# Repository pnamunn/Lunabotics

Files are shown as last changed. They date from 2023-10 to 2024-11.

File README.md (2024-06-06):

# NASA Lunabotics 2024 Competition - Team ARES for SDSU
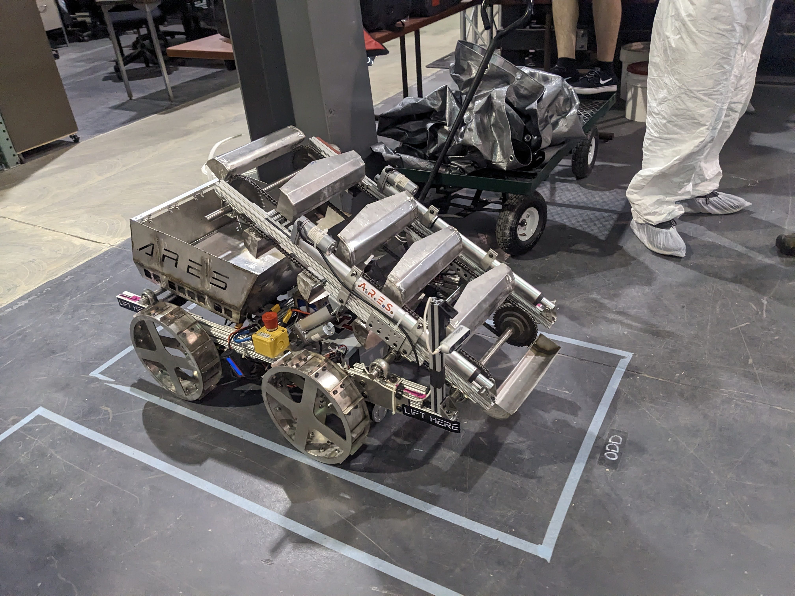
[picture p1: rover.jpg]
Rover picture


## Distros used:
Using Ubuntu 20.04 LTS on Jetson & Ubuntu 22.04 LTS on laptop.  ROS2 foxy on Jetson & ROS2 humble on laptop.  Different ROS2 versions shouldn't affect their ability to work together over a network.  
Python packages needed for controls:  rclpy, pyserial, sensor_msgs, bitarray  
Python packages needed for modified Vulcan video stream:  cv2, pyrealsense2, flask, numpy  

## Rover telecoms set up:
Ensure laptop & Jetson are both connected to the ARES_WAP

`ros2 run joy joy_node` on laptop to detect Logitech controller

`minicom -D /dev/<arduino_USB_port> -b 500000` on Jetson to serial monitor the Arduino Mega

`python3 serial_joystick.py` on Jetson

<run vulcan video stream on Jetson command>

<connect to appropriate IP address to view video stream on laptop>

## Passwords:
| Device | Username | Password | |
| :---: | :---: | :---: | :---: |
| Laptop | steui | WARHAWK | |
| Jetson | stubert  | S2P@C619 | |
| WAP connection | ARES_WAP | 72878781 | |
| WAP config settings | admin | DoctorShaffar<3 | Website: tplinkwifi.net |

## On Arduino Mega hat:
J17 connects to PB6 (drivetrain R) & PB5(drivetrain L)  
J18 connects to DH3 (exc tilt) & PL4 (depo tilt)  
J19 connects to DH5 (exc height) & PH4 (exc chain)  

## Logitech controller buttons mapping:
| Control | Use |
| ---: | :---  |
| Left joystick  | Drivetrain controls |
| Right joystick | Camera gimble controls |
| B or X | Excavation chain fwd or backward |
| Y or A | Excavation frame move up or down |
| LB or LT | Depo bin tilt out or in |
| RB or RT | Excavation frame tilt out or in  |

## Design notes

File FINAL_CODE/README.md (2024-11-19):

### In competition, the following code was used to control the rover:

- serial_joystick.py : 
	- Input: ROS2 datatypes describing the current state of the gamepad's joysticks & buttons
	- Output: Encoded serial bytes of the gamepad's state changes
- ARES_Embedded.c : 
	- Input: Encoded serial bytes of the gamepad's state changes
	- Output: 16-bit PWM signals for motors & actuators
- vulcan_camera_modified.py :
	- *Input:* Frames from the Intel Realsense camera
	- *Output:* A Flask app, accessible by other devices on the same network, that shows a grayscale video stream  

### Before competition, the following code was finished and successfully tested individually, but the team did not have enough time to intergrate them with the rest of the C code on one microcontroller:

- current_sensors.c
	- Input: 
	- Output: Prints current readings from 2 sensors, as floating points with 3 sig figs
- loadcell_sensor.c
	- Input: 4 strain gauges in Wheatstone configuration, fed through the HX711 ADC/PGA
	- Output: Prints detected weight 
- proximity_sensors.c
	- Input: 
	- Output: Prints distance from detected obstacle & blocks drivetrain movement if obstacle becomes too close

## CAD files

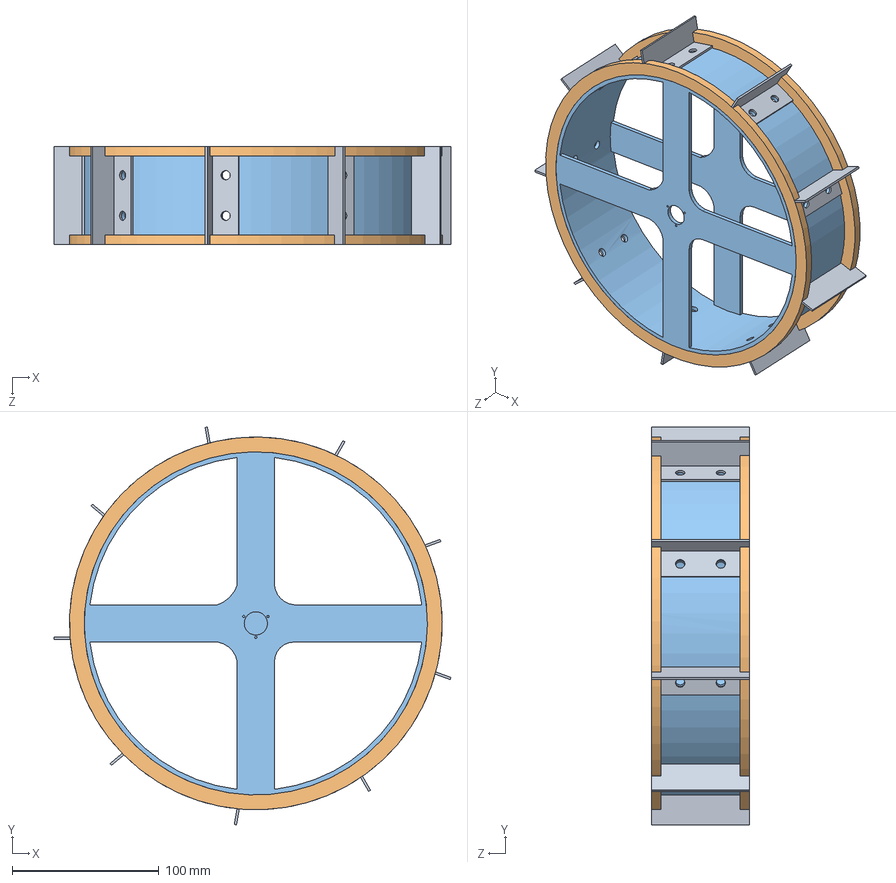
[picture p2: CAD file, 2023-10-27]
CAD/GrouserWheel/Full Grouser Wheel.SLDASM
270.5 x 271.1 x 66.7 mm
Grouser Wheel
Grouser Wheel Rim x 2
Grouser x 9

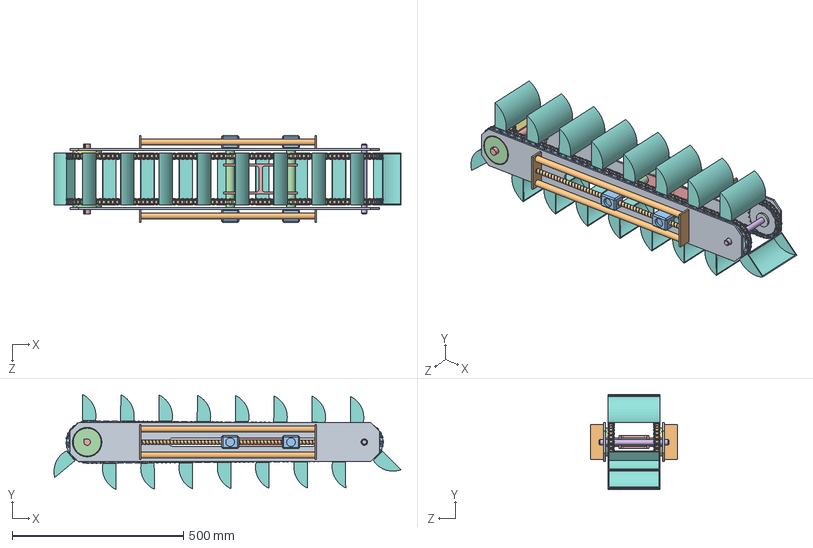
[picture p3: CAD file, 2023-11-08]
CAD/HADES CAD/Excavation/Excavation Belt Sub Asm.SLDASM
1013.8 x 277.9 x 254.0 mm
6663K201_ANSI Roller Chain Idler Sprocket x 2
7265K326_Adding Link for ANSI Number 40H Heavy Duty Roller Chain x 153
7265K324_Connecting Link for ANSI Number 40H Heavy Duty Roller Chain x 154
6236K156_Roller Chain Sprocket
Drive_Key
1346K24_Rotary Shaft
Mirror6236K156_Roller Chain Sprocket
scoop x 17
Side_Panel x 2
Linear Actuator x 2
Acuator Sleeve x 4
Fixing Rod x 2
Fixed Rod Seperator

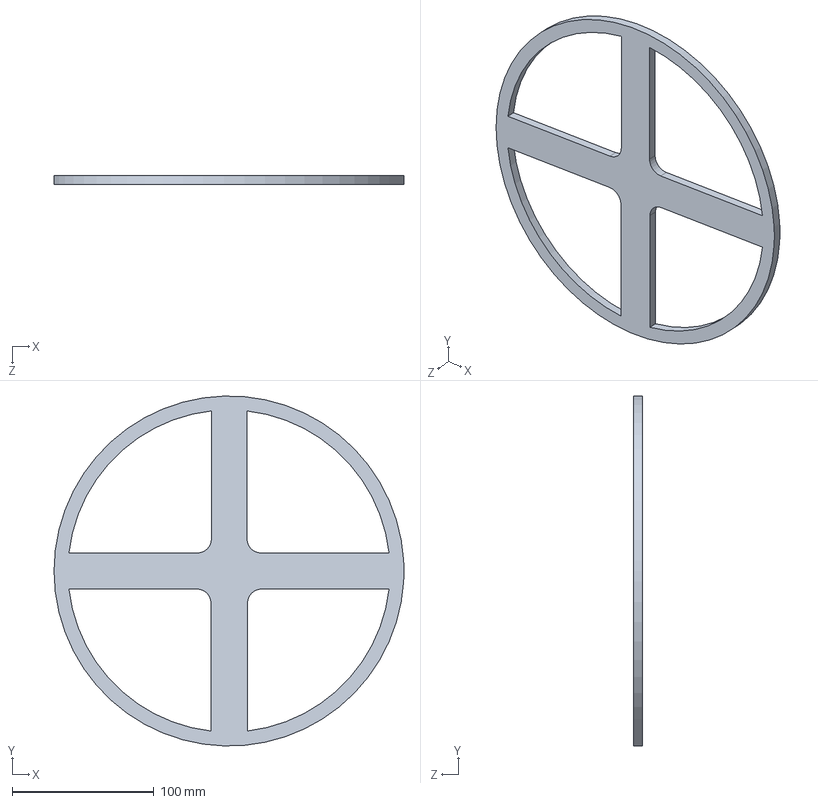
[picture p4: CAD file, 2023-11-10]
CAD/GrouserWheel/18Grouser Wheel/Grouser Wheel Rim front.SLDPRT
247.1 x 247.0 x 6.35 mm

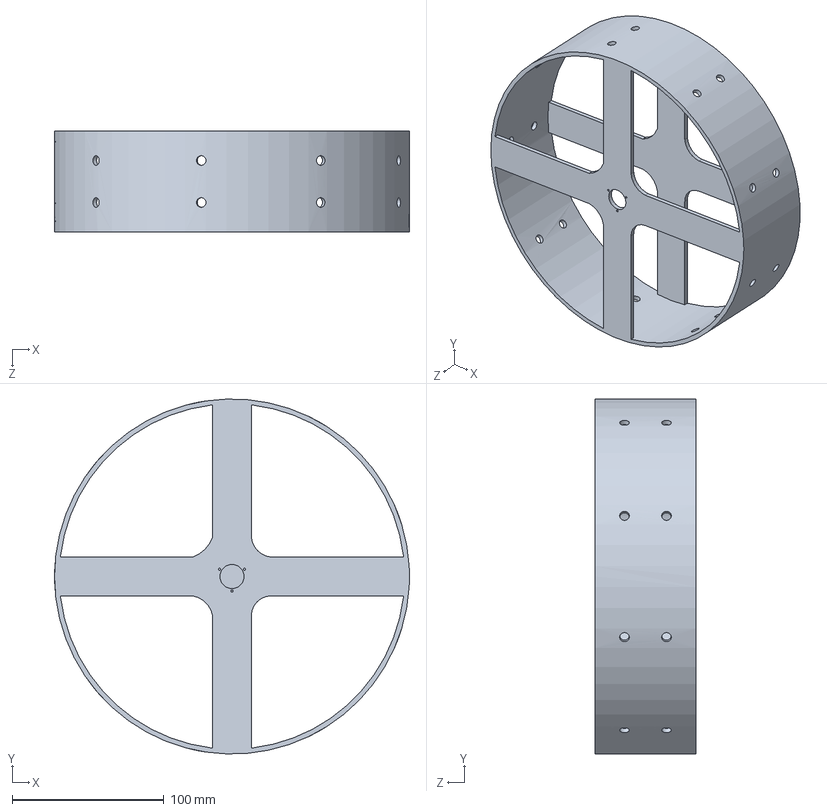
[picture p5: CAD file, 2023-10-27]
CAD/GrouserWheel/Grouser Wheel.SLDPRT
233.8 x 233.7 x 66.7 mm

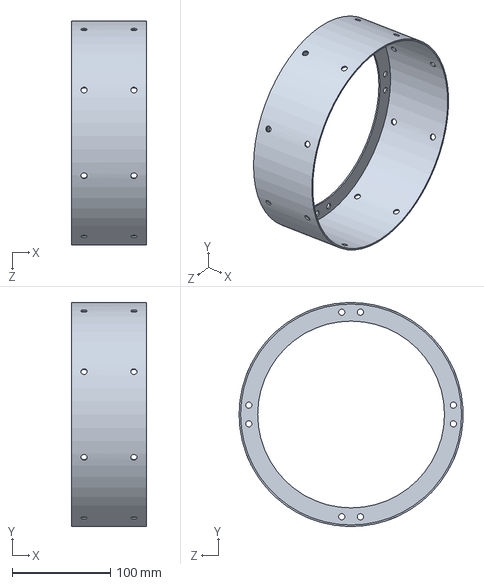
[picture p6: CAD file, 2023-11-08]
CAD/HADES CAD/Chassis/Copy of Wheel_Rim.SLDPRT
76.2 x 228.5 x 228.4 mm

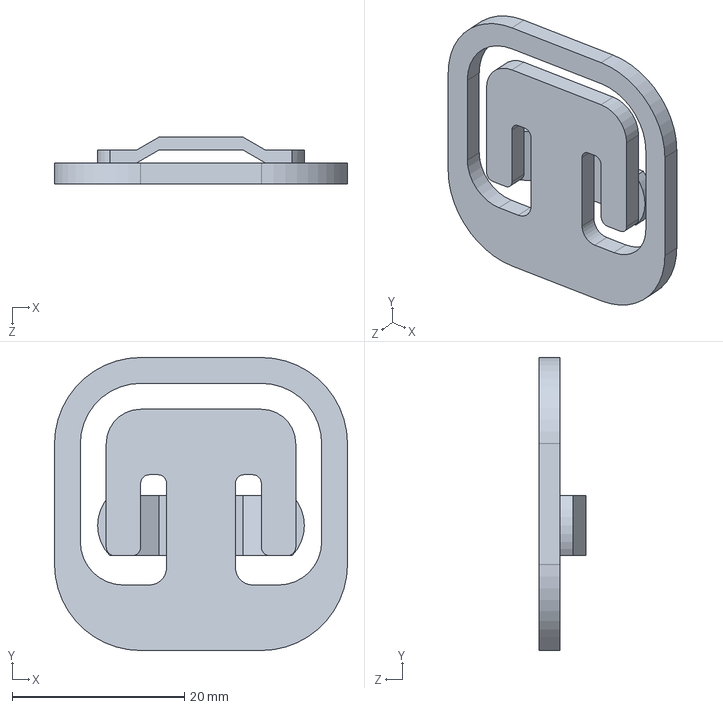
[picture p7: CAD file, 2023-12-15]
CAD/Load Cell Part.SLDPRT
34.0 x 34.0 x 5.40 mm

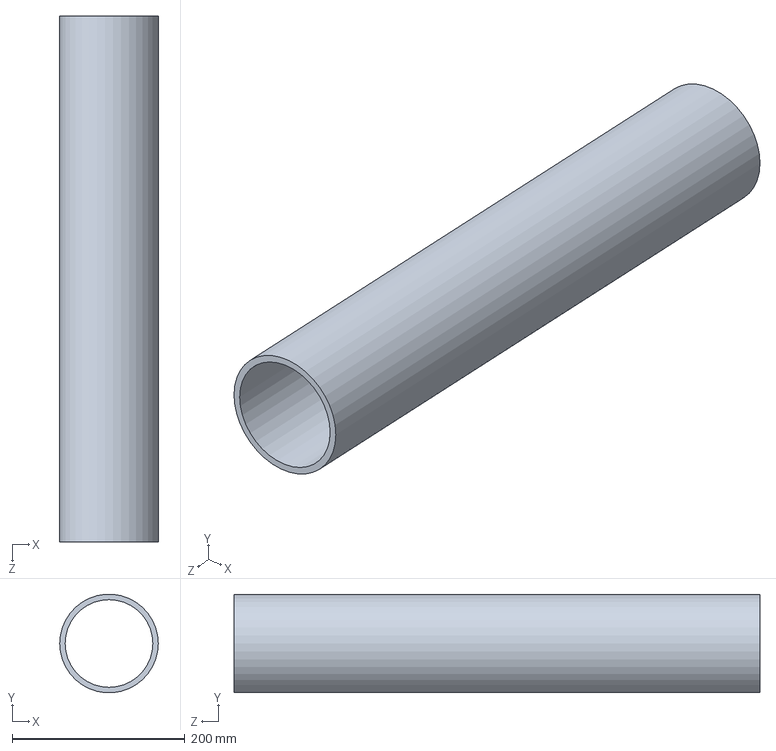
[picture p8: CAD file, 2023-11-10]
CAD/Wield Excavation Trial/2ft-9056K324_Multipurpose 6061 Aluminum Round Tube.SLDPRT
114.3 x 113.9 x 609.6 mm

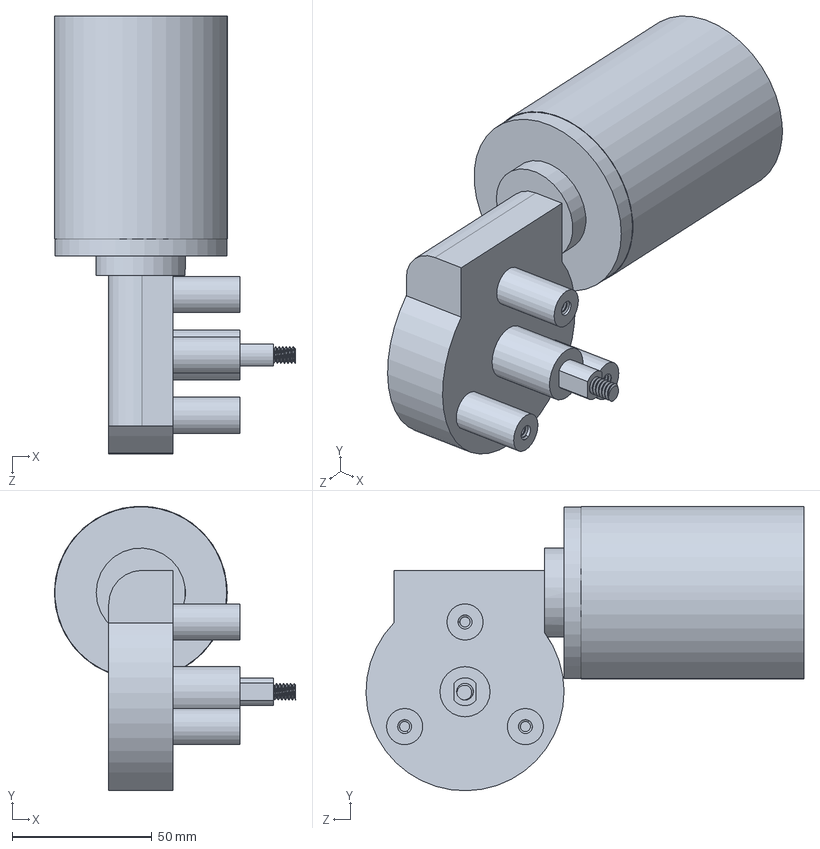
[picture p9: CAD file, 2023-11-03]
KiCad/24V 80 W 6Nm Brush.SLDPRT
86.5 x 102.0 x 157.0 mm

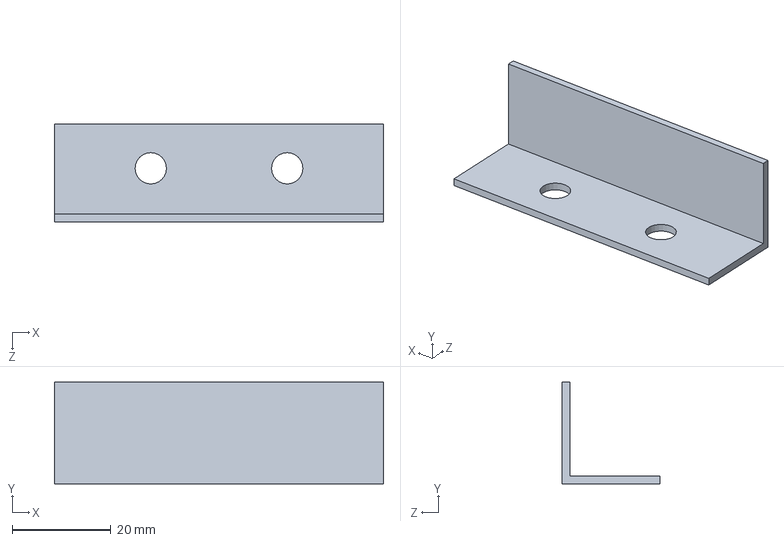
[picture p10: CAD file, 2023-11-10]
CAD/GrouserWheel/18Grouser Wheel/Grouser.SLDPRT
66.7 x 20.6 x 19.8 mm

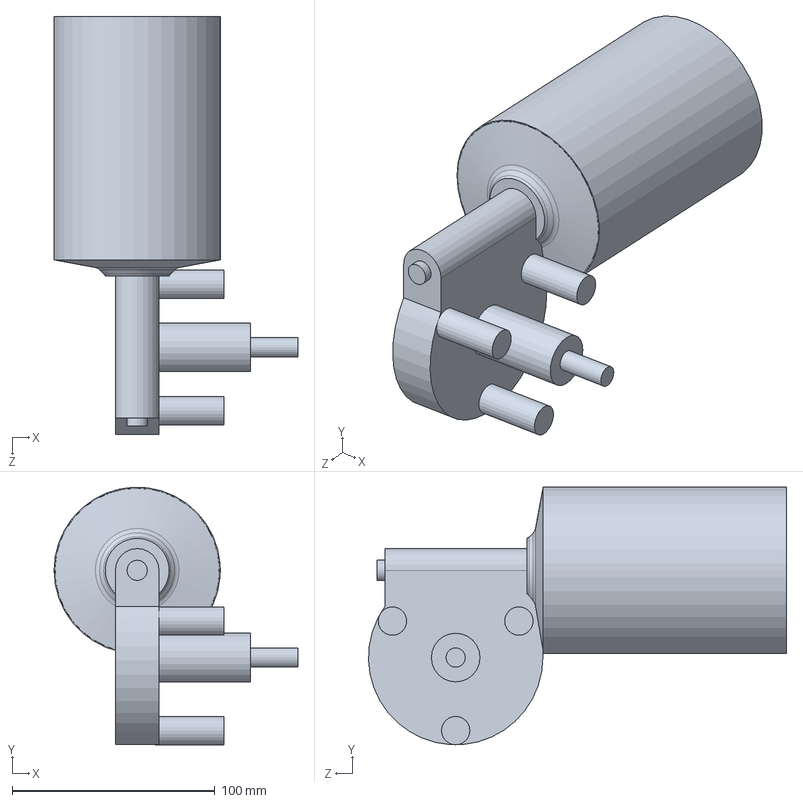
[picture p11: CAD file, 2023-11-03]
KiCad/12V 100W 8 Nm motor.SLDPRT
120.2 x 127.0 x 206.1 mm

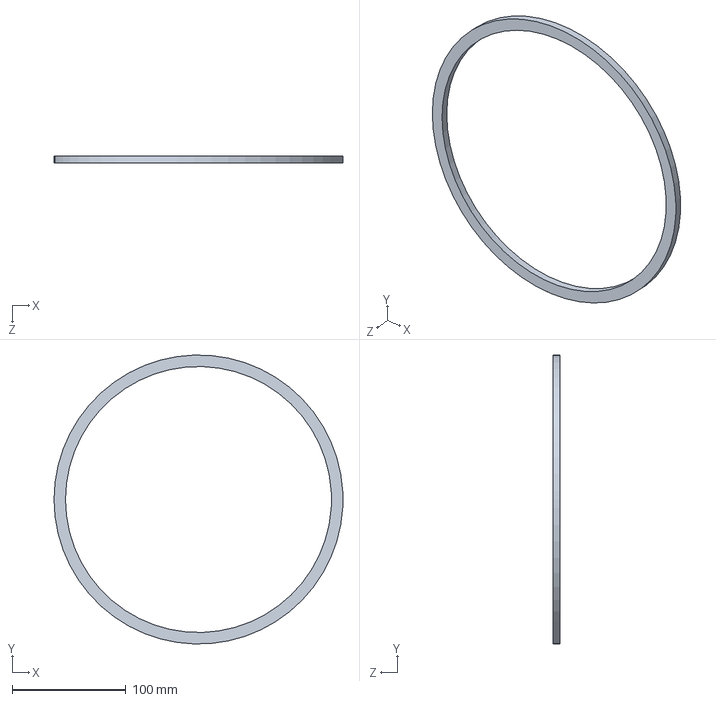
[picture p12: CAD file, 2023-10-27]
CAD/GrouserWheel/Grouser Wheel Rim.SLDPRT
254.0 x 253.9 x 6.35 mm

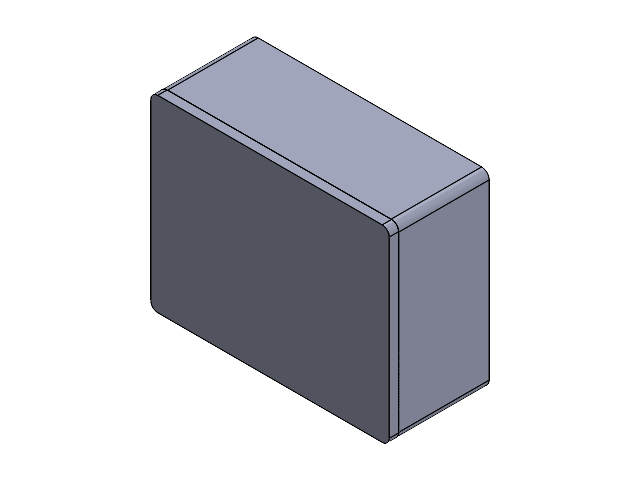
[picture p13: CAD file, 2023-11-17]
CAD/Electrical Housing Box Assembly Ares.SLDASM
box top

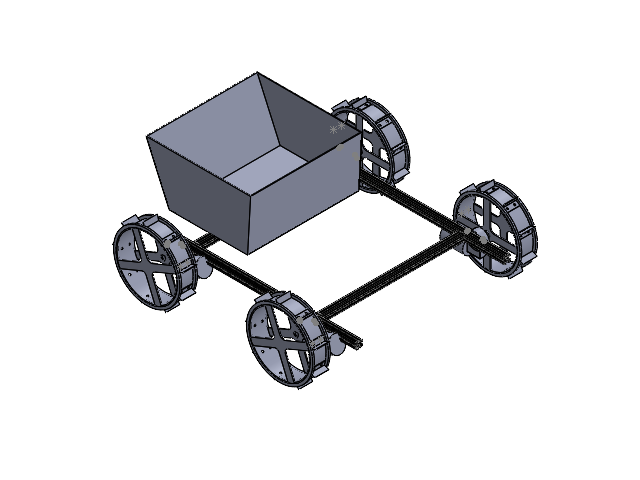
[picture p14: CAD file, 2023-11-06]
CAD/Simple Model.SLDASM
47065T411_T-Slotted Framing x 4
Grouser_Wheel x 4
Grouser_Wheel_Rim x 8
Wheel_Mount x 4
Grouser x 36
MotorForWheel x 4
Hooper

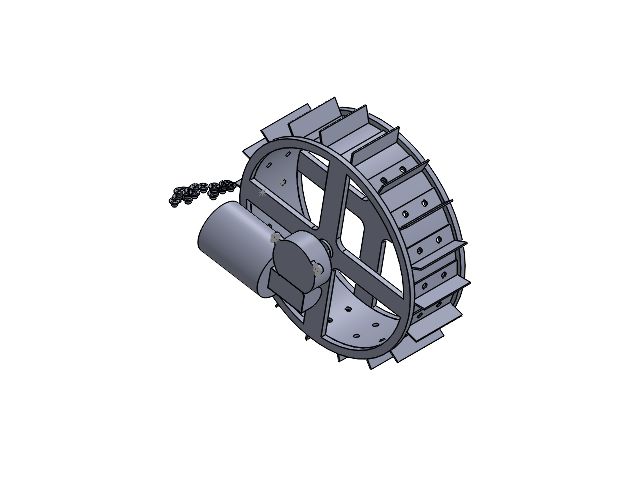
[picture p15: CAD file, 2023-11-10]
CAD/GrouserWheel/18Grouser Wheel/Full Grouser Wheel 18Grouser.SLDASM
Grouser Wheel 20Degree
Grouser Wheel Rim front
Grouser Wheel Rim motor mount
Grouser x 18
MotorForWheel
Wheel Mount
WheelBolt x 18

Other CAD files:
CAD/Wield Excavation Trial/WieldHelp.SLDASM
CAD/HADES CAD/Deposition/Deposition SubASM.SLDASM
CAD/HADES CAD/Excavation/Mirror6236K156_Roller Chain Sprocket.SLDPRT
CAD/GrouserWheel/18Grouser Wheel/Grouser Wheel Rim motor mount.SLDPRT
CAD/47065T411_T-Slotted Framing.SLDPRT
CAD/GrouserWheel/18Grouser Wheel/Grouser Wheel 20Degree.SLDPRT
CAD/GrouserWheel/18Grouser Wheel/MotorForWheel.SLDPRT
CAD/GrouserWheel/18Grouser Wheel/Wheel Mount.SLDPRT
CAD/GrouserWheel/18Grouser Wheel/WheelBolt.SLDPRT
CAD/GrouserWheel/Grouser.SLDPRT
CAD/HADES CAD/Chassis/Copy of 1346K24_Rotary Shaft.SLDPRT
CAD/HADES CAD/Chassis/Copy of 3136N275_T-Slotted Framing.SLDPRT
CAD/HADES CAD/Chassis/Copy of 47065T149_T-Slotted Framing.SLDPRT
CAD/HADES CAD/Chassis/Copy of 47065T241_Silver Corner Bracket.SLDPRT
CAD/HADES CAD/Chassis/Copy of 47065T601_T-Slotted Framing.SLDPRT
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

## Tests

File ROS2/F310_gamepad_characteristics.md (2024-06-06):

# How the Logitech F310 gamepad acts

On D, with mode light on:
    left joystick has x and y axis values of [-1,1] with 0 being neutral
    right joystick has x and y axis values of [0,255] with 127 or 128 being neutral

## USE THIS ONE :
On D, with mode light off:
    both joysticks have x and y axis values of [0,255] with 127 or 128 being neutral
        in joy, this becomes [-1,1] 32 bit float with 16 decimal places with 0 being neutral
    all buttons and triggers are boolean

On X, with mode light on:
    left joystick has x and y axis values of [-1,1] with 0 being neutral
    right joystick has x and y axis values of [-32768, 32767] with 128 being neutral for x, -129 being neutral for y

On X, with mode light off:
    both joysticks have x and y axis values of [-32768, 32767] with 128 being neutral for x, -129 being neutral for y

## On D, with mode light off controller mappings:

msg.buttons = {
    [0]     X
    [1]     A
    [2]     B
    [3]     Y
    [4]     LB
    [5]     RB
    [6]     LT
    [7]     RT
    [8]     back
    [9]     start
    [10]    Left stick press
    [11]    Right stick press
} 

msg.axes = {
    [0]     Left stick x axis
    [1]     Left stick y axis
    [2]     Right stick x axis
    [3]     Right stick y axis
    [4]     D pad left & right
    [5]     D pad up & down
}

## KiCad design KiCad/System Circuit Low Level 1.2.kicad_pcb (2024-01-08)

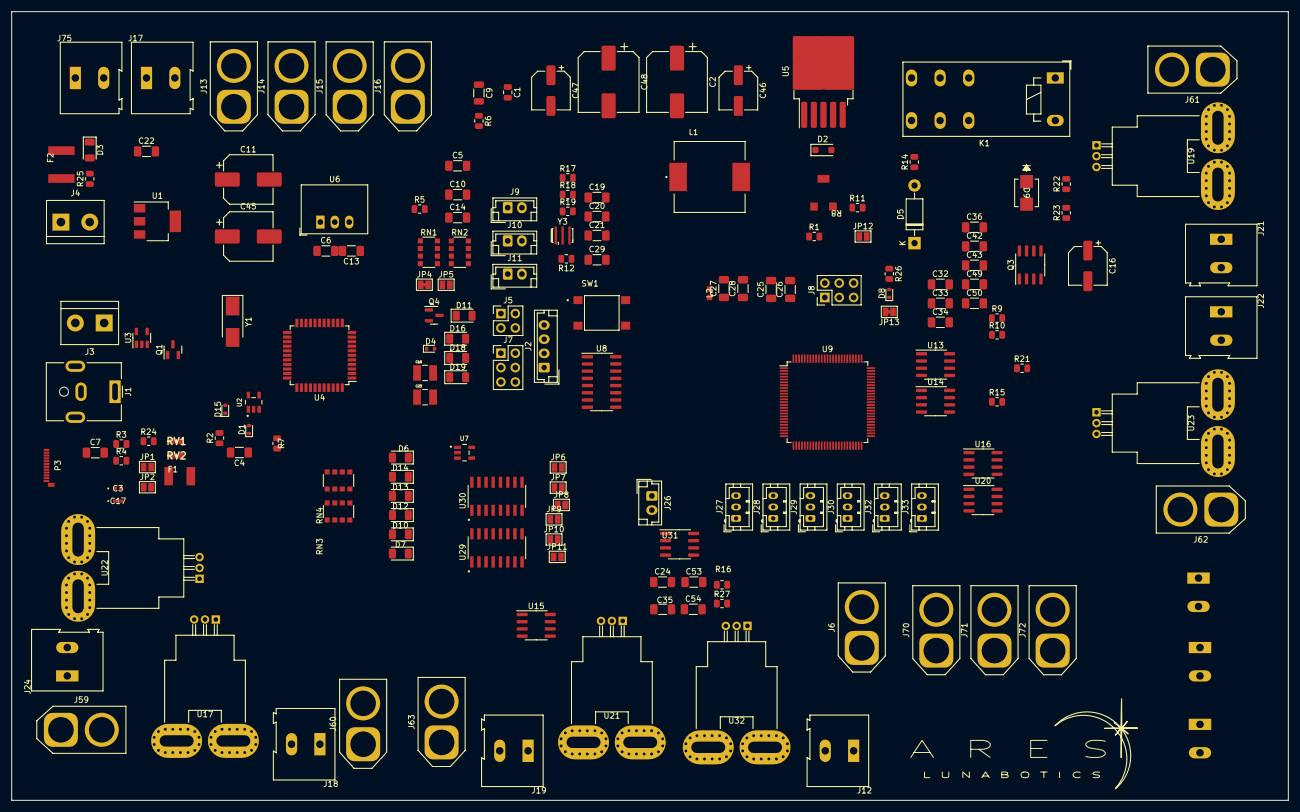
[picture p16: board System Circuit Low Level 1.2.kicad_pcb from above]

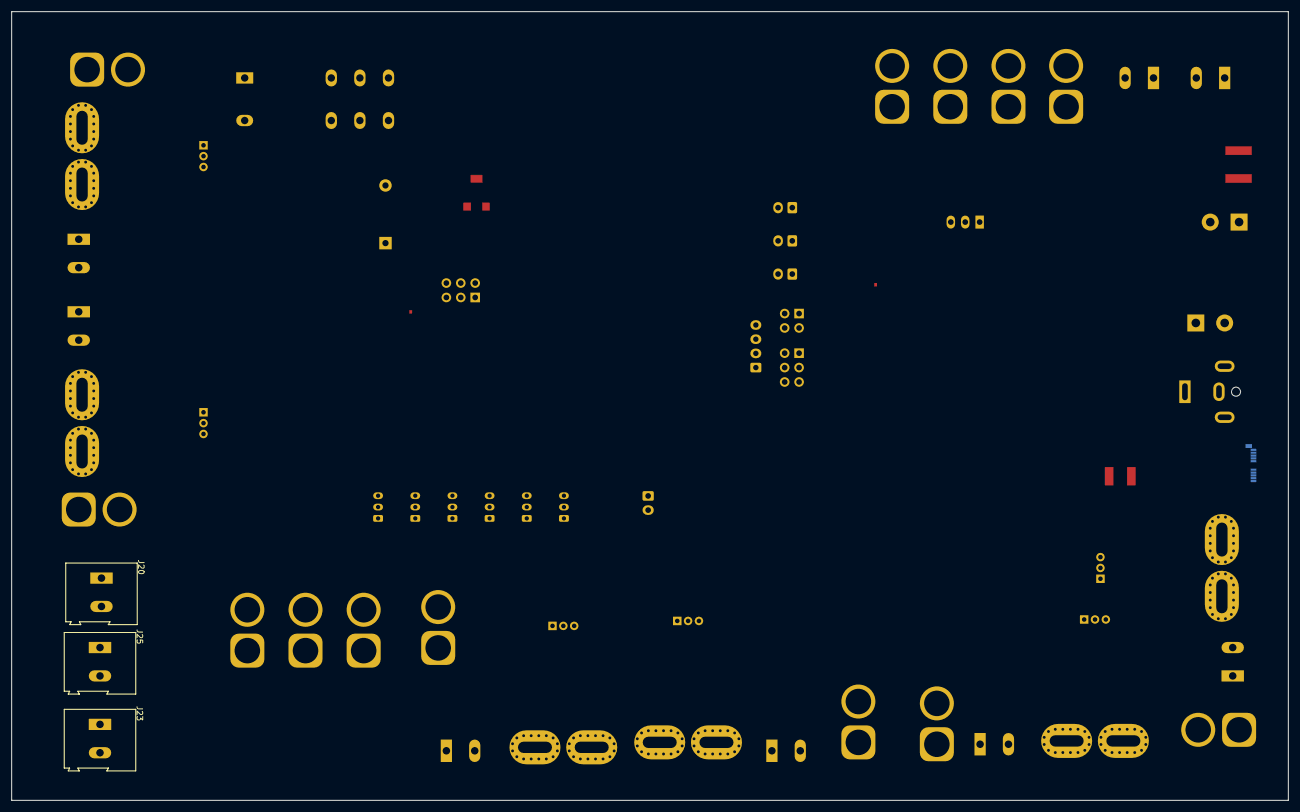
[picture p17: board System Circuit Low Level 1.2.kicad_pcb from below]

Board: 2 copper layers, 225.0 x 139.0 mm, 178 parts (3 on the bottom side), 121 nets, no tracks yet.

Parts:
C1: 100n; C_0805_2012Metric
C2, C48: 100u; CP_Elec_10x10.5
C3, C17: 22p; CAP_GCM155_MUR
C4, C5, C7, C10, C13, C14, C19, C21, C22, C24, C25, C26, C27, C28, C29, C32, C33, C34, C35, C36: 0.1u; C_1206_3216Metric_Pad1.33x1.80mm_HandSolder
C6: 0.33u; C_1206_3216Metric_Pad1.33x1.80mm_HandSolder
C9: 330p; C_1206_3216Metric
C11, C45: 47u; CP_Elec_8x10.5
C16, C46, C47: 10u; CP_Elec_6.3x5.8
C18, C23: 10u; CAPC3225X270N
C20: 0.022u; C_1206_3216Metric_Pad1.33x1.80mm_HandSolder
C42, C43, C49, C50, C53, C54: 10n; C_1206_3216Metric_Pad1.33x1.80mm_HandSolder
D1, D4, D8, D15: 1N4148WT; D_SOD-523
D2: MBR1020VL; D_SOD-123F
D3, D6, D7, D10, D11, D12, D13, D14, D16, D18, D19: LED; LED_1206_3216Metric
D5: 1N5819; D_DO-41_SOD81_P10.16mm_Horizontal
D9: 3A100Vstd; SMB_STM
F1: FuseF-MSMF050-2; FuseF-MSMF050-2-sty1
F2: 3A_tr 1.5A_hld Slow Burn; MF-SMDF
J1: Barrel_Jack_Switch; BarrelJack_CUI_PJ-063AH_Horizontal
J2: Conn_01x04; JST_EH_B4B-EH-A_1x04_P2.50mm_Vertical
J3, J4: Screw_Terminal_01x02; TerminalBlock_bornier-2_P5.08mm
J5: Conn_02x02_Odd_Even; PinHeader_2x02_P2.54mm_Vertical
J6, J13, J14, J15, J16, J59, J60, J61, J62, J63, J70, J71, J72: XT-90F-vert; AMASS_XT60-F_1x02_P7.20mm_Vertical
J7, J8: Conn_02x03_Odd_Even; PinHeader_2x03_P2.54mm_Vertical
J9, J10, J11, J26: Conn_01x02; JST_EH_B2B-EH-A_1x02_P2.50mm_Vertical
J12, J17, J18, J19, J20, J21, J22, J23, J24, J25, J75: Screw_Terminal_01x02; TerminalBlock_Altech_AK300-2_P5.00mm
J27, J28, J29, J30, J32, J33: Conn_01x03; JST_PH_B3B-PH-K_1x03_P2.00mm_Vertical
JP1, JP2, JP5, JP6, JP7, JP8, JP9, JP10, JP11, JP12: SolderJumper_2_Open; SolderJumper-2_P1.3mm_Open_Pad1.0x1.5mm
JP4, JP13: SolderJumper_2_Bridged; SolderJumper-2_P1.3mm_Bridged_Pad1.0x1.5mm
K1: RT314A12; Relay_SPDT_Schrack-RT1-16A-FormC_RM5mm
L1: 33u; IND_SRP1265A-330M
L2: 10u; IND_LQM18DN_70_MUR
P3: USB_C_Plug_USB2.0; USB_C_Plug_Molex_105444
Q1: HM2301B; SOT-23
Q3: IRF7403; SOIC-8_3.9x4.9mm_P1.27mm
Q4: S8550D; SOT-23
R1, R22, R23: 100k; R_0805_2012Metric
R2, R7, R26: 10k; R_0805_2012Metric
R3, R12: 1M; R_0805_2012Metric
R4, R24: 22; R_0805_2012Metric
R5: 8.2k; R_0805_2012Metric
R6, R25: 680; R_0805_2012Metric
R8: 5k; 3314G-2-500E
R9, R10, R15, R16, R17, R19, R21, R27: 100; R_0805_2012Metric
R11: 120k; R_0805_2012Metric
R14: 4.7K; R_0805_2012Metric
R18: 20k; R_0805_2012Metric
RN1, RN2, RN3, RN4: 102-1k R Net; R_Array_Convex_4x1206
RV1, RV2: BRNCG063MLC-05E; VARC1608X55N
SW1: SW_Push_Dual; SW_TS07-667-25-BK-100-SMT-TR
U1: LD1117S50TR_SOT223; SOT-223-3_TabPin2
U2, U7: LMV358; SOT95P280X145-5N
U3: LP2985-3.3; SOT-23-5
U4: ATmega32U4-A; TQFP-44_10x10mm_P0.8mm
U5: LM2596S-12; TO-263-5_TabPin3
U6: R-78E9.0-0.5; Converter_DCDC_RECOM_R-78E-0.5_THT
U8: HX711; SOP-16_3.9x9.9mm_P1.27mm
U9: ATmega2560-16A; TQFP-100_14x14mm_P0.5mm
U13, U14, U15, U16, U20, U31: TLC2272; SOIC-8_3.9x4.9mm_P1.27mm
U17, U19, U21, U22, U23, U32: ACS758xCB-050B-PFF; Allegro_CB_PFF
U29, U30: CD4053B; SOIC127P600X175-16N
Y1: Crystal; Crystal_SMD_Abracon_ABM3-2Pin_5.0x3.2mm_HandSoldering
Y3: CSTCE16M0V53-R0; Resonator_SMD_Murata_CSTxExxV-3Pin_3.0x1.1mm_HandSoldering

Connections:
1AX: JP6.2 (B), U16.1 (1OUT), U16.2 (1IN-), U29.12 (A0)
1AY: R21.1, U22.3 (VIOUT), U29.13 (A1)
1BX: JP7.2 (B), U13.1 (1OUT), U13.2 (1IN-), U29.2 (B0)
1BY: R9.1, U17.3 (VIOUT), U29.1 (B1)
1CX: JP8.2 (B), U14.1 (1OUT), U14.2 (1IN-), U29.5 (C0)
1CY: R10.1, U19.3 (VIOUT), U29.3 (C1)
2AX: JP9.2 (B), U20.1 (1OUT), U20.2 (1IN-), U30.12 (A0)
2AY: R15.1, U23.3 (VIOUT), U30.13 (A1)
2BX: JP10.2 (B), U15.1 (1OUT), U15.2 (1IN-), U30.2 (B0), U31.1 (1OUT), U31.2 (1IN-)
2BY: R16.1, R27.1, U21.3 (VIOUT), U30.1 (B1), U32.3 (VIOUT)
2CX: JP11.2 (B), U30.5 (C0)
12V Set-Point: JP12.2 (B), R1.2, U5.4 (FB)
+3V3: U2.2 (-), U3.5 (VOUT)
+5V: C10.1, C11.1, C24.1, C25.1, C26.1, C27.1, C32.1, C33.1, C34.1, C35.1, C36.1, D4.1 (K), J7.2, J8.2, J27.2, J28.2, JP13.1 (A), L2.2, Q1.3 (S), RN2.6, RN2.7, RN2.8, RN3.5, RN3.6, RN3.7, RN3.8, RN4.3, RN4.4, U1.2 (VO), U3.1 (VIN), U3.3 (ON/~OFF), U4.14 (VCC), U4.24 (AVCC), U4.34 (VCC), U4.44 (AVCC), U9.10 (VCC), U9.31 (VCC), U9.61 (VCC), U9.80 (VCC), U13.8 (VDD+), U14.8 (VDD+), U15.8 (VDD+), U16.8 (VDD+), U17.1 (VCC), U19.1 (VCC), U20.8 (VDD+), U21.1 (VCC), U22.1 (VCC), U23.1 (VCC), U29.16 (VDD), U30.16 (VDD), U31.8 (VDD+), U32.1 (VCC)
+9V: C13.1, J29.1, J30.1, J32.1, J33.1, U6.3 (OUT)
+12V: C1.1, C2.1, C6.1, C9.1, C46.1, C47.1, C48.1, D3.2 (A), L1.2, R11.2, U6.1 (IN)
+S: C19.1, J2.3, R17.2
-E PROX: C1.2, C2.2, C3.1, C4.2, C6.2, C7.2, C10.2, C11.2, C13.2, C14.1, C16.2, C17.1, C18.2, C20.2, C21.1, C22.1, C23.2, C24.2, C25.2, C26.2, C27.2, C28.2, C32.2, C33.2, C34.2, C35.2, C36.2, C42.2, C43.2, C45.2, C46.2, C47.2, C48.2, C49.2, C50.2, C53.2, C54.2, D2.2 (A), D6.1 (K), D7.1 (K), D10.1 (K), D11.1 (K), D12.1 (K), D13.1 (K), D14.1 (K), D19.1 (K), J1.2, J2.2, J4.2, J7.6, J8.6, J17.1, J27.3, J28.3, J29.3, J30.3, J32.3, J33.3, JP1.1 (A), JP1.2 (B), JP2.1 (A), JP5.2 (B), Q3.1 (S), Q3.2 (S), Q3.3 (S), R1.1, R5.1, R6.2, R7.1, R23.2, R25.1, RN1.1, SW1.1, SW1.3, U1.1 (GND), U3.2 (GND), U4.5 (UGND), U4.15 (GND), U4.23 (GND), U4.35 (GND), U4.43 (GND), U5.3 (GND), U5.5 (~ON/OFF), U6.2 (GND), U8.5 (AGND), U8.9 (INB-), U8.10 (INB+), U8.14 (XI), U8.15 (RATE), U9.11 (GND), U9.32 (GND), U9.62 (GND), U9.81 (GND), U9.99 (GND), U13.4 (GND), U14.4 (GND), U15.4 (GND), U16.4 (GND), U17.2 (GND), U19.2 (GND), U20.4 (GND), U21.2 (GND), U22.2 (GND), U23.2 (GND), U29.7 (VEE), U29.8 (VSS), U30.7 (VEE), U30.8 (VSS), U31.4 (GND), U32.2 (GND)
-S: C19.2, J2.4, R19.2
E+: C18.1, J2.1, Q4.3 (C), R18.2, U8.3 (AVDD)
E-SWTCH IN: D9.1 (K), J17.2, J75.1, K1.11, K1.A2, R14.1, R22.1
MISO: J8.1, U9.22 (PB3)
MOSI: J8.4, U9.21 (PB2)
unnamed: C9.2, R6.1
unnamed: D1.2 (A), J3.1
unnamed: D2.1 (K), L1.1, U5.2 (OUT)
unnamed: D3.1 (K), R25.2
unnamed: D5.2 (A), K1.14, R14.2
unnamed: D5.1 (K), U5.1 (VIN)
unnamed: D6.2 (A), RN3.1
unnamed: D7.2 (A), RN3.2
unnamed: D8.1 (K), JP13.2 (B), R26.1
unnamed: D9.2 (A), K1.A1, Q3.5 (D), Q3.6 (D), Q3.7 (D), Q3.8 (D)
unnamed: D10.2 (A), RN3.3
unnamed: D11.2 (A), RN2.4
unnamed: D12.2 (A), RN3.4
unnamed: D13.2 (A), RN4.5
unnamed: D14.2 (A), RN4.6
unnamed: D15.2 (A), J1.1
unnamed: D16.2 (A), RN2.3
unnamed: D16.1 (K), U4.22 (PD5)
unnamed: D18.2 (A), RN2.2
unnamed: D18.1 (K), U4.25 (PD4)
unnamed: D19.2 (A), RN2.1
unnamed: P3.A4 (VBUS), P3.A9 (VBUS), P3.B4 (VBUS), P3.B9 (VBUS)
unnamed: J5.1, U4.28 (PB4)
unnamed: J5.2, U4.30 (PB6)
unnamed: J5.3, U4.29 (PB5)
unnamed: J5.4, U4.12 (PB7)
unnamed: J7.1, U4.11 (PB3)
unnamed: J7.3, U4.9 (PB1)
unnamed: J7.4, U4.10 (PB2)
unnamed: J12.2, U32.4 (IP+)
unnamed: J18.2, U17.4 (IP+)
unnamed: J19.2, U21.4 (IP+)
unnamed: J21.2, U19.4 (IP+)
unnamed: J22.2, U23.4 (IP+)
unnamed: J24.2, U22.4 (IP+)
unnamed: J27.1, U7.3 (+), U9.26 (PB7)
unnamed: J29.2, U9.46 (PD3)
unnamed: J30.2, U9.6 (PE4)
unnamed: J32.2, U9.45 (PD2)
unnamed: J33.2, U9.7 (PE5)
unnamed: JP2.2 (B), U4.42 (AREF)
unnamed: C20.1, JP4.1 (A)
unnamed: C14.2, JP5.1 (A), U9.98 (AREF)
unnamed: JP6.1 (A), U9.77 (PA1), U29.14 (A)
unnamed: JP7.1 (A), U9.76 (PA2), U29.15 (B)
unnamed: JP8.1 (A), U9.75 (PA3), U29.4 (C)
unnamed: JP9.1 (A), U9.74 (PA4), U30.14 (A)
unnamed: JP10.1 (A), U9.73 (PA5), U30.15 (B)
unnamed: JP11.1 (A), U9.72 (PA6), U30.4 (C)
unnamed: JP12.1 (A), R11.1
unnamed: P3.A6 (D+), R4.1, RV2.1
unnamed: P3.A7 (D-), R24.1, RV1.1
unnamed: P3.A1 (GND), P3.A12 (GND), P3.B1 (GND), P3.B12 (GND)
unnamed: P3.S1 (SHIELD), RV1.2, RV2.2
unnamed: C7.1, Q1.1 (D), U4.2 (UVCC), U4.7 (VBUS)
unnamed: Q1.2 (G), U2.1
unnamed: C16.1, Q3.4 (G), R22.2, R23.1
unnamed: Q4.2 (B), U8.2 (BASE)
unnamed: C23.1, Q4.1 (E), U8.1 (VSUP), U8.16 (DVDD)
unnamed: C4.1, R2.1, R7.2, U2.3 (+)
unnamed: R24.2, U4.4 (D+)
unnamed: R4.2, U4.3 (D-)
unnamed: RN1.6, U4.20 (PD2)
unnamed: RN1.7, U4.21 (PD3)
unnamed: C5.1, RN1.8, U4.27 (PD7)
unnamed: C3.2, R3.1, U4.17 (XTAL1), Y1.2
unnamed: C17.2, R3.2, U4.16 (XTAL2), Y1.1
unnamed: RN2.5, U7.1, U7.2 (-)
unnamed: U8.12 (DOUT), U9.41 (PL6)
unnamed: R17.1, U8.8 (INA+)
unnamed: R19.1, U8.7 (INA-)
unnamed: U8.11 (PD_SCK), U9.42 (PL7)
unnamed: C21.2, U8.6 (VBG)
unnamed: R5.2, R18.1, U8.4 (VFB)
unnamed: C28.1, L2.1, U9.100 (AVCC)
unnamed: RN1.2, U9.2 (PE0)
unnamed: RN1.3, U9.3 (PE1)
unnamed: R12.2, U9.34 (XTAL1), Y3.1
unnamed: R12.1, U9.33 (XTAL2), Y3.2
unnamed: C43.1, R9.2, U13.3 (1IN+)
unnamed: C49.1, R10.2, U14.3 (1IN+)
unnamed: C53.1, R16.2, U15.3 (1IN+)
unnamed: C42.1, R21.2, U16.3 (1IN+)
unnamed: C50.1, R15.2, U20.3 (1IN+)
unnamed: C54.1, R27.2, U31.3 (1IN+)
RESET1: C5.2, D8.2 (A), J8.5, JP4.2 (B), R26.2, SW1.2, SW1.4, U9.30 (~RESET)
RESET2: D4.2 (A), J7.5, U4.13 (~RESET)
SCK: J8.3, U9.20 (PB1)
Sig - CAM Y: J28.1, U9.5 (PE3)
Sig - DEPO BIN TILT: J26.2, U9.25 (PB6)
Sig - EXC ASC/DSC: J26.1, U9.24 (PB5)
Sig - EXCV TILT: J11.2, U9.17 (PH5)
Sig - Ex Sprckt: J11.1, U9.16 (PH4)
Sig - L1: J9.1, U9.38 (PL3)
Sig - L2: J9.2, U9.39 (PL4)
Sig - R1: J10.1, U9.40 (PL5)
Sig - R2: J10.2, U9.15 (PH3)
V-IN: C22.2, C45.1, D1.1 (K), D15.1 (K), R2.2, U1.3 (VI)

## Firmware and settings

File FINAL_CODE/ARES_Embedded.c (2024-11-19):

/*
Program:		ARES_Embedded.c
Authors:		Stuart Pollmann & Patricia Munn

Use Case:		Flashed to ATMega 2560 (Arduino Mega) on-board the rover.
				Code receives 5 byte messages serially from the on-board Jetson
				Orin Nano before sending those on as PWM signals to command the
				motors and linear actuators.  Code also prints out (Txs) what
				commands are being sent so that the user can monitor the system
				from the UI laptop.

				This C code was used in final version of the rover, worked correctly.
				Commented out is the right joystick code that would have controlled
				the camera gimble, but that code never tested or used bc the team
				never got the camera gimble mounted.  Also commented out is the
				setDIR_serial() function, which works and can be used to send commands
				to the rover using keyboard buttons rather than the controller.


Functionality:	Program is interrupt driven.  When Arduino receives a byte from
				the Jetson, the ISR(USART0_RX_vect) is triggered, which stores
				the byte in the heard_msg.data array.  Once all 5 bytes of the 
				message are received and stored in the array, the MSG_handler()
				function has a switch case that looks at the message type (the 
				first byte received, which is heard_msg.data[0] ) and processes
				the message based on what type it is.
				The message type can be either '1' for buttons or '2' for left
				joystick movement.  If the message type is neither of these 
				values, the default case is used, which throws away the received
				message and prints 'dflt' to the terminal.

				There also exists a watchdog timer that goes off every ~6 s and
				kill all rover movement.  This mitigates the risk of a runaway
				situation (where the rover continually runs the last command
				received), which can occur if the data sync is thrown off or
				if the rover loses network connection.


Room for		Currently, the code is robust with the robot acting on all gamepad commands with very little latency.  Rarely do 'dflt' cases occur and
Improvements:	they do not throw off the communication sync between the Jetson & Arduino.
				Though making code changes on the C or Python side seem to
				cause more and more 'dflt' cases to occur and throw off the communication
				synchronization between the Jetson & Arduino.

				Root cause of this: the Jetson is sending bytes faster than the
				Arduino is able to store and take them out of the Rx buffer.  The 
				Arduino's Rx buffer can hold 2 bytes before it is full.  Once full,
				the next byte will be thrown out and lost (a data overrun condition).
				A byte being lost throws off the data synchronization between the 
				Jetson & Arduino: for all subsequent messages, the message type
				won't be correctly stored at heard_msg.data[0], causing the 'dflt'
				case to occur.  To observe if a data overrun condition happens,
				print out DOR0 (Data Overrun), Bit 3 of the UCSR0A register, 
				after a UART ISR trigger.

				Proposed fixes: maybe a longer time.sleep() delay being added
				between byte sends in Python could mitigate this.  A smarter 
				and more robust fix would be to add error checking and correction
				in the C code.  When an error in synchronization is detected, the
				Arduino could tell the Jetson there's an error, throw away that
				data, and reset both devices to send/expect to receive the 
				message type byte next.

Datasheets
used:			https://ww1.microchip.com/downloads/en/devicedoc/atmel-2549-8-bit-avr-microcontroller-atmega640-1280-1281-2560-2561_datasheet.pdf													
*/

#include <avr/io.h>
#include <avr/interrupt.h>
#include <stdio.h>
#include <stdlib.h>


//-----TIMER 1 FAST PWM SETTING MACROS----------------------//
#define T1A_COM_HI		(TCCR1A	|=  (1<<COM1A1)	| (1<<COM1B1)| (1<<COM1C1));
#define T1A_COM_LO		(TCCR1A	&= ~(1<<COM1A0)	&~(1<<COM1B0)&~(1<<COM1C0));								   
#define T1A_WGM_HI		(TCCR1A	|=	(1<<WGM11));
#define T1A_WGM_LO		(TCCR1A	&= ~(1<<WGM10));
#define T1B_WGM_HI		(TCCR1B	|=	(1<<WGM12) |  (1<<WGM13));
#define T1A_CS__LO		(TCCR1B	&= ~(1<< CS12)	&~(1<<CS10));
#define T1B_CS__HI		(TCCR1B	|=	(1<< CS11));

#define FPWM_1A_OUT		(DDRB	|=	(1<<PINB5));
#define FPWM_1B_OUT		(DDRB	|=	(1<<PINB6));
#define FPWM_1C_OUT		(DDRB	|=	(1<<PINB7));


//-----TIMER 3 FAST PWM SETTING MACROS----------------------//
#define T3A_COM_HI		(TCCR3A	|=  (1<<COM3A1)	| (1<<COM3B1)| (1<<COM3C1));
#define T3A_COM_LO		(TCCR3A	&= ~(1<<COM3A0)	&~(1<<COM3B0)&~(1<<COM3C0));
#define T3A_WGM_HI		(TCCR3A	|=	(1<<WGM31));
#define T3A_WGM_LO		(TCCR3A	&= ~(1<<WGM30));
#define T3B_WGM_HI		(TCCR3B	|=	(1<<WGM32) |  (1<<WGM33));
#define T3A_CS__LO		(TCCR3B	&= ~(1<< CS32)	&~(1<<CS30));
#define T3B_CS__HI		(TCCR3B	|=	(1<< CS31));

#define FPWM_4A_OUT		(DDRE	|=	(1<<PINE3));
#define FPWM_4B_OUT		(DDRE	|=	(1<<PINE4));
#define FPWM_4C_OUT		(DDRE	|=	(1<<PINE5));


//-----TIMER 4 FAST PWM SETTING MACROS----------------------//
#define T4A_COM_HI		(TCCR4A	|=  (1<<COM4A1)	| (1<<COM4B1)| (1<<COM4C1));
#define T4A_COM_LO		(TCCR4A	&= ~(1<<COM4A0)	&~(1<<COM4B0)&~(1<<COM4C0));
#define T4A_WGM_HI		(TCCR4A	|=	(1<<WGM41));
#define T4A_WGM_LO		(TCCR4A	&= ~(1<<WGM40));
#define T4B_WGM_HI		(TCCR4B	|=	(1<<WGM42) |  (1<<WGM43));
#define T4A_CS__LO		(TCCR4B	&= ~(1<< CS42)	&~(1<< CS40));
#define T4B_CS__HI		(TCCR4B	|=	(1<< CS41));

#define FPWM_2A_OUT		(DDRH	|=	(1<<PINH3));
#define FPWM_2B_OUT		(DDRH	|=	(1<<PINH4));
#define FPWM_2C_OUT		(DDRH	|=	(1<<PINB5));


//-----TIMER 5 FAST PWM SETTING MACROS----------------------//
#define T5A_COM_HI		(TCCR5A	|=  (1<<COM5A1)	| (1<<COM5B1)| (1<<COM5C1));
#define T5A_COM_LO		(TCCR5A	&= ~(1<<COM5A0)	&~(1<<COM5B0)&~(1<<COM5C0));
#define T5A_WGM_HI		(TCCR5A	|=	(1<<WGM51));
#define T5A_WGM_LO		(TCCR5A	&= ~(1<<WGM50));
#define T5B_WGM_HI		(TCCR5B	|=	(1<<WGM52) |  (1<<WGM53));
#define T5A_CS__LO		(TCCR5B	&= ~(1<< CS52)	&~(1<< CS50));
#define T5B_CS__HI		(TCCR5B	|=	(1<< CS51));

#define FPWM_3A_OUT		(DDRL	|=	(1<<PINL3));
#define FPWM_3B_OUT		(DDRL	|=	(1<<PINL4));
#define FPWM_3C_OUT		(DDRL	|=	(1<<PINL5));


//-----SABERTOOTH CONTROLLER MACROS-------------------------//
#define FWD_DUTY16	 3999
#define STOP_DUTY16	 2999
#define RVRS_DUTY16  1999
#define HALF_FWD_DUTY16		3499
#define HALF_RVRS_DUTY16	2499

#define TOP_40HZ	39999

#define DRIVE_L		OCR1A	// Arduino pin 11, PB5
#define DRIVE_R		OCR1B	// pin 12, PB6
// #define SERVO_L		OCR1C	// pin 13, PB7
// #define SERVO_R		OCR3A	// pin 5, PE3
#define DEPO_TILT	OCR5B	// pin 45, PL4
#define EXC_TILT	OCR4A	// pin 6, PH3
#define EXC_CHAIN	OCR4B	// pin 7, PH4
#define EXC_HEIGHT	OCR4C	// pin 8, PH5

volatile	uint8_t DIRencoder = 0X00;
volatile	char	key		   =    0;


//-----WATCHDOG OVERRIDE MACROS---------------------------//
#define		WATCH_DOG_EN		(TIMSK5|=(1<<TOIE5));		// EN timer5 overflow interrupt
volatile	uint8_t		WatchToken = 0;


//-----MSG HANDLING MACROS--------------------------------//
#define MAX_MSG_LENGTH					5					// max # of words in a msg
volatile uint8_t buttons[8]		=	{0};					// button bit field

typedef struct message						// struct holding variables related to msgs
{
		volatile uint8_t werd_count;		
		volatile uint8_t data[MAX_MSG_LENGTH];						//array to store all the words in a message
} message;

volatile struct message heard_msg;		// creates a message struct instance


//-----FUNCTION PROTOTYPES--------------------------------//
void serial_transmit(uint8_t data);
void term_Send_Val_as_Digits(uint8_t val);
void printBin8(uint8_t stuff);
void stop_motors();
void stop_linear_actuators();
void signal_linear_actuators();
void MSG_handler();



//-----INIT FUNCTIONS----------------------------------------//

void uart_init (void)						//initialize UART
{
	UBRR0L = 1;								//BAUD 500000
	
	UCSR0B	|=	(1<<	TXEN0)
			|	(1<<	RXEN0)					
			|	(1<<	RXCIE0);			//EN: Interrupt
											//EN: receiver/transmitter
	
	UCSR0C	|=	(1<<	UCSZ00)
			|	(1<<	UCSZ01);			//8-bit char size
}


void gpio_init()							//in's and out's
{
	SCK_SIG_OUT
	HX711_DAT_IN
	
	NORTH_SENS_IN
	SOUTH_SENS_IN
	
	FPWM_1A_OUT
	FPWM_1B_OUT
	FPWM_1C_OUT
	
	FPWM_2A_OUT
	FPWM_2B_OUT
	FPWM_2C_OUT
	
	FPWM_3A_OUT
	FPWM_3B_OUT
	FPWM_3C_OUT
	
	FPWM_4A_OUT
	FPWM_4B_OUT
	FPWM_4C_OUT
}


void timer1_init()						// For Drivetrain & Servo Left
{
	T1A_WGM_HI								//FPWM Mode
	T1A_WGM_LO
	T1B_WGM_HI
	T1A_CS__LO								//P.S. 8
	T1B_CS__HI	
	T1A_COM_HI								//Match:Clear
	T1A_COM_LO								//Bottom:Set
	
	ICR1	=	TOP_40HZ;					//40Hz 1.5ms Pulse
	
	OCR1A	=	STOP_DUTY16;				// DRIVE_L
	OCR1B	=	STOP_DUTY16;				// DRIVE_R	
	OCR1C	=	STOP_DUTY16;				// SERVO_L
}


void timer3_init()						// For Servo Right
{
	T3A_WGM_HI								//FPWM Mode
	T3A_WGM_LO
	T3B_WGM_HI
	T3A_CS__LO								//P.S. 8
	T3B_CS__HI
	T3A_COM_HI								//Match:Clear
	T3A_COM_LO								//Bottom:Set

	ICR3	=	TOP_40HZ;					//40Hz 1.5ms Pulse
	
	OCR3A	=	STOP_DUTY16;				// SERVO_R
	OCR3B	=	STOP_DUTY16;				//Available
	OCR3C	=	STOP_DUTY16;				//Available
}


void timer4_init()						// For Excavation
{
	T4A_WGM_HI								//FPWM Mode
	T4A_WGM_LO
	T4B_WGM_HI
	T4A_CS__LO								//P.S. 8
	T4B_CS__HI
	T4A_COM_HI								//Match:Clear
	T4A_COM_LO								//Bottom:Set

	ICR4	=	TOP_40HZ;					//40Hz 1.5ms Pulse
	
	OCR4A	=	STOP_DUTY16;				// EXC_TILT
	OCR4B	=	STOP_DUTY16;				// EXC_CHAIN
	OCR4C	=	STOP_DUTY16;				// EXC_HEIGHT
}


void timer5_init()						// For Watchdog & Depo
{
	T5A_WGM_HI								//FPWM Mode
	T5A_WGM_LO
	T5B_WGM_HI
	T5A_CS__LO								//P.S. 8
	T5B_CS__HI
	T5A_COM_HI								//Match:Clear
	T5A_COM_LO								//Bottom:Set

	WATCH_DOG_EN							//Watchdog on

	ICR5	=	TOP_40HZ;					//40Hz 1.5ms Pulse
	
	OCR5A	=	STOP_DUTY16;				//Available
	OCR5B	=	STOP_DUTY16;				// DEPO_TILT
	OCR5C	=	STOP_DUTY16;				//Available
}



//-----UART TX FUNCTIONS-----------------------------------------//

void serial_transmit (uint8_t data)		//Tx serial
{
	//UDR0 |= (0 << TXB80);
	while (!( UCSR0A & (1<<UDRE0)));		//w8 b4 read;
											//UDREn is read when 1
	UDR0 = data; 							//write the data in register
}


void term_Send_Val_as_Digits(uint8_t val)	//Decimal
{
	uint8_t digit = '0';					//Initialize
	
	while(val >= 100)						//incoming hundred's
	{
		digit	+= 1;						//count
		val		-= 100;						//chunks of hundred
	}
	
	serial_transmit(digit);					//Send to serial
	digit = '0';							//initialize
	
	while(val >= 10)						//Remaining ten's
	{
		digit	+= 1;						//count
		val		-= 10;						//chunks of ten
	}
	
	serial_transmit(digit);					//Send to Serial
	serial_transmit('0' + val);				//Send remainder Value
}


void printBin8(uint8_t stuff)				//Binary Print
{
	for(uint8_t n = 0; n < 8; n++)			//Print data: MSB to LSB
	{
		uint8_t tm_ = (stuff >> (7 - n)) & (0x01);		// shift highest AND remaining

		if(tm_)
		{
			serial_transmit('1');			//Send 1
		}
		else
		{
			serial_transmit('0');			//Send 0
		}
	}
}



//-----HELPER FUNCTIONS--------------------------------------------//

void stop_motors()		// initialize all motor direction to be stopped
{
	DRIVE_L		= STOP_DUTY16;
	DRIVE_R		= STOP_DUTY16;
	// SERVO_L		= STOP_DUTY16;
	// SERVO_R		= STOP_DUTY16;
}


void stop_linear_actuators() 
{
	DEPO_TILT = STOP_DUTY16;
	EXC_TILT = STOP_DUTY16;
	EXC_CHAIN = STOP_DUTY16;
	EXC_HEIGHT = STOP_DUTY16;
}


void signal_linear_actuators()
{
	switch (heard_msg.data[1])
	{
		case 0x80:					// exc chain back  X
			EXC_CHAIN = RVRS_DUTY16;
			serial_transmit('c');
			serial_transmit('b');			
		break;
			
			
		case 0x40:					// exc height down  A
			EXC_HEIGHT = HALF_FWD_DUTY16;
			serial_transmit('e');
			serial_transmit('d');
			break;
			
			
		case 0x20:					// exc chain fwd  B
			EXC_CHAIN = FWD_DUTY16;
			serial_transmit('c');
			serial_transmit('f');
		break;
			
			
		case 0x10:					// exc height up  Y
			EXC_HEIGHT = HALF_RVRS_DUTY16;
			serial_transmit('e');
			serial_transmit('u');
		break;
		
		
		case 0x08:					// depo tilt fwd  LB
			DEPO_TILT = FWD_DUTY16;
			serial_transmit('d');
			serial_transmit('f');
		break;
		
		
		case 0x04:					// exc tilt fwd  RB
			EXC_TILT = HALF_FWD_DUTY16;
			serial_transmit('e');
			serial_transmit('f');
		break;
		
		
		case 0x02:					// depo tilt back  LT
			DEPO_TILT = RVRS_DUTY16;
			serial_transmit('d');
			serial_transmit('b');
		break;
		
		
		case 0x01:					// exc tilt back  RT
			EXC_TILT = HALF_RVRS_DUTY16;
			serial_transmit('e');
			serial_transmit('b');
		break;

		// Pressing two buttons at once:
		case 0x60:					// exc height down + exc chain fwd    A + B
			EXC_HEIGHT = HALF_FWD_DUTY16;
			EXC_CHAIN = FWD_DUTY16;
			serial_transmit('e');
			serial_transmit('d');
			serial_transmit('&');
			serial_transmit('c');
			serial_transmit('f');
		break;
		

		case 0x30:					// exc height up + exc chain fwd    Y + B
			EXC_HEIGHT = HALF_RVRS_DUTY16;
			EXC_CHAIN = FWD_DUTY16;
			serial_transmit('e');
			serial_transmit('u');
			serial_transmit('&');
			serial_transmit('c');
			serial_transmit('f');
		break;
		

		case 0xC0:					// exc height down + exc chain backward    A + X
			EXC_HEIGHT = HALF_FWD_DUTY16;
			EXC_CHAIN = RVRS_DUTY16;
			serial_transmit('e');
			serial_transmit('d');
			serial_transmit('&');
			serial_transmit('c');
			serial_transmit('b');
		break;
		

		case 0x90:					// exc height up + exc chain backward    Y + X
			EXC_HEIGHT = HALF_RVRS_DUTY16;
			EXC_CHAIN = RVRS_DUTY16;
			serial_transmit('e');
			serial_transmit('u');
			serial_transmit('&');
			serial_transmit('c');
			serial_transmit('b');
		break;
		
		
		default:
			serial_transmit('s');
			serial_transmit('t');
			serial_transmit('a');
			serial_transmit('h');
			serial_transmit('p');
			stop_linear_actuators();
		break;
	}
}



//-----CONTROLS----------------------------------------------//

//void setDIR_serial(char input)		// controls using the keyboard
//{
	//char tosend='A';						//Place holder
	//
	////-----DRIVETRAIN COMMAND FUNCTIONS-------------------//
	//
	//if(input=='a')
	//{										//Crck Scrw L
		//
		//DRIVE_L = FWD_DUTY16;
		//DRIVE_R = RVRS_DUTY16;
		//
		//DIRencoder = 0x01;					//Encrypt DIR set
		//tosend='L';							//Encrypt State Measure
		//
	//}
	//
	//else if (input=='d')
	//{										//Crck Scrw R
		//DRIVE_L = RVRS_DUTY16;
		//DRIVE_R= FWD_DUTY16;
		//
		//DIRencoder = 0X08;					//Encrypt DIR set
		//tosend='R';							//Encrypt State Measure
//
	//}
	//
	//else if (input=='w')
	//{										//Forward
		//DRIVE_L = FWD_DUTY16;
		//DRIVE_R = FWD_DUTY16;
		//
		//DIRencoder	=	0X0D;				//Encrypt DIR set
		//tosend		=	'F';				//Encrypt State Measure
		//
	//}
	//
	//else if (input=='s')					//Backward
	//{
		//
		//DRIVE_L = RVRS_DUTY16;
		//DRIVE_R = RVRS_DUTY16;
		//
		//DIRencoder = 0X0C;					//Encrypt DIR set
		//tosend='B';							//Encrypt State Measure
	//}
	//else if (input=='m')				// left joystick is in deadzone, Stop
	//{
		//DRIVE_L = STOP_DUTY16;
		//DRIVE_R = STOP_DUTY16;
	//}
	//
	////-----EXCAVATION COMMAND FUNCTIONS-----------------------//
	//
	//else if (input == '1')
	//{
		//EXC_TILT = RVRS_DUTY16;
		//tosend='D';							//down
	//}
	//
	//else if (input == '2')
	//{
		//EXC_TILT = STOP_DUTY16;
		//tosend='S';							//stop
	//}
	//
	//else if (input == '3')
	//{
		//EXC_TILT =	FWD_DUTY16;
		//tosend='U';							//up
	//}
	//
	//else if (input == '7')
	//{
		//EXC_CHAIN = FWD_DUTY16;i
		//tosend='W';							//CW
	//}
	//else if (input == '8')
	//{
		//EXC_CHAIN =	RVRS_DUTY16;
		//tosend='C';							//CCW
	//}
	//else if (input == '9')
	//{
		//EXC_CHAIN = STOP_DUTY16;
		//tosend='S';							//stop
	//}
	//
	//else if (input == 'j')
	//{
		//DEPO_TILT = FWD_DUTY16;
		//tosend='U';							//up
	//}
	//else if (input == 'k')
	//{
		//DEPO_TILT = STOP_DUTY16;
		//tosend='S';							//stop
	//}
	//else if (input == 'l')
	//{
		//DEPO_TILT = RVRS_DUTY16;
		//tosend='D';							//down
	//}
	//
	//else
	//{
		//init_DIR();
		//
		//DIRencoder = 0X00;					//Encrypt DIR set
		//tosend='S';							//Encrypt State Measure
	//}
	//
	//serial_transmit(tosend);				//Send State to serial
	//serial_transmit('\n');
	//serial_transmit('\r');
	//
//}


void MSG_handler()			// reads msg_type and takes appropriate actions
{
	serial_transmit('m');
	serial_transmit('s');
	serial_transmit('g');
	serial_transmit(':');
	serial_transmit(' ');
	
	uint8_t msg_type = heard_msg.data[0];

	switch(msg_type)				// decodes the message, based on what type of message it is
	{
		case '1':										// message was for buttons
	
			serial_transmit('B');
			serial_transmit('\t');		
			
			signal_linear_actuators();
			WatchToken = 0;
		
		break;
	
		case '2':								// message was for the left joystick
		
			serial_transmit('L');
			serial_transmit('\t');
		
			// sets duty cycles of the left & right motors
			DRIVE_L = (heard_msg.data[1] << 8) | heard_msg.data[2];
			DRIVE_R = (heard_msg.data[3] << 8) | heard_msg.data[4];

			//for (uint8_t i = 0; i < 5; i++)		// can check your data received by printing them out in binary
			//{
				//printBin8(heard_msg.data[i]);
				//serial_transmit(' ');
			//}
			WatchToken = 0;		// reset watchdog count

		break;
	
		// case '3':								// message was for the right joystick
		
		// 	serial_transmit('R');
		// 	serial_transmit('\t');
		
		// 	// sets duty cycles of the left & right servos for the gimble
		// 	SERVO_L = (heard_msg.data[1] << 8) | heard_msg.data[2];
		// 	SERVO_R = (heard_msg.data[3] << 8) | heard_msg.data[4];

		// 	//for (uint8_t i = 0; i < 5; i++)		// can check your data received by printing them out in binary
		// 	//{
		// 		//printBin8(heard_msg.data[i]);
		// 		//serial_transmit(' ');
		// 	//}
		// 	WatchToken = 0;		// reset watchdog count

		// break;
	
		default:								// if the msg_type is not a recognizable value
			
			serial_transmit('\t');
			serial_transmit('\t');
	
			serial_transmit('d');
			serial_transmit('f');
			serial_transmit('l');
			serial_transmit('t');

		break;
	}
		
	serial_transmit('\n');	// formatting
	serial_transmit('\n');
	serial_transmit('\r');
	
	heard_msg.data[0] = 0;		// reset vals to 0, just in case
	heard_msg.data[1] = 0;
	heard_msg.data[2] = 0;
	heard_msg.data[3] = 0;
	heard_msg.data[4] = 0;
}



//-----ISRs-------------------------------------------------//

ISR(TIMER5_OVF_vect)		// for watchdog
{
	cli();

	if(WatchToken == 240)					//kill operations
	{
		stop_motors();
		stop_linear_actuators();
		WatchToken = 0;
		
		serial_transmit('\n');
		
		serial_transmit('Z');				//notify Terminal
		serial_transmit('O');
		serial_transmit('I');
		serial_transmit('N');
		serial_transmit('K');
		serial_transmit('S');

		serial_transmit('\n');				//Print nxt on
		serial_transmit('\r');				//new line
	}
	
	WatchToken++;

	sei();
}


ISR(USART0_RX_vect)		// for receiving bytes from the Jetson
{
	cli();									//disable interrupts

	heard_msg.data[heard_msg.werd_count] = UDR0;
	
	serial_transmit(heard_msg.werd_count + '0');
	serial_transmit(' ');
	//printBin8(heard_msg.data[heard_msg.werd_count]);
	//serial_transmit(' ');
	serial_transmit(heard_msg.data[heard_msg.werd_count]);
	serial_transmit(' ');
	//printBin8(UCSR0A);
	
	serial_transmit('\n');
	serial_transmit('\r');
	
	heard_msg.werd_count++;
	
	if (heard_msg.werd_count >= MAX_MSG_LENGTH)		// handle msg & reset werd_count
	{
		MSG_handler(&heard_msg);
		heard_msg.werd_count = 0;
	}

	sei();
}



//-----MAIN------------------------------------------------//

int main(void)
{
	cli();

	gpio_init();
	stop_motors();
	stop_linear_actuators();
	uart_init();
	timer1_init();
	timer3_init();
	timer4_init();
	timer5_init();
	heard_msg.werd_count = 0;

	serial_transmit('i');
	serial_transmit('n');
	serial_transmit('i');
	serial_transmit('t');
	
	serial_transmit('\n');
	
    sei();
	
    while (1) 
    {
		
    }
}

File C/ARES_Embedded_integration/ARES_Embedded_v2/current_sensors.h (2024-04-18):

/*
 * Current sensors' code
 * Author:  Anabel Sanchez
 */ 

#ifndef	CURRENTSENSORS_h
#define CURRENTSENSORS_h


#define F_CPU 16000000UL   	 // 16MHz
#include <util/delay.h>
#include <stdbool.h>

#include "serialTxfunctions.h"


#define Vcc 4.872
#define arr_size 10

float voltage = 0.0;
float current = 0.0;
float sum1 = 0.0;
float sum2 = 0.0;

volatile int i = 0;
volatile int j = 0;
volatile uint16_t array1[arr_size] = {0};
volatile uint16_t array2[arr_size] = {0};


typedef struct current_alert
{
	volatile bool flag;		// 1 if a threshold was reached
	volatile uint8_t motor;		// which motor
	volatile uint8_t sign;		// + or - sign
	volatile float data;
} current_alert;


volatile struct current_alert current_alert_L = {0, 'L'};		// Left drivetrain current sensor
//current_alert_L.motor = 'L';

volatile struct current_alert current_alert_R = {0, 'R'};		// Right drivetrain current sensor
//current_alert_R.motor = 2;




void sensor_ADC_init() {
	ADCSRA |= (1<<ADEN);	// enable ADC
							// ADATE bit is initialized to 0 for manual conversion
							// manually trigger using ADSC
	ADCSRA |= (1<<ADIE);	// enable ADC conversion complete interrupt
	ADCSRA |= (1<<ADPS0) | (1<<ADPS1) | (1<<ADPS2); // prescale 128
	ADMUX |= (1<<REFS0);	// AVcc is our reference voltage
	ADMUX |= (1<<MUX0);		// ADC1, PF1
	//ADCSRA |= (1<<ADSC);	// start first conversion; as long as this is 1, conversions will keep happening
}


//grabs ADC value from registers, finds the rolling average ADC value, normalizes the value,
//then checks that value against the set thresholds, if within thresholds, flags & stores data

ISR (ADC_vect) {
	static uint16_t ADC_low = 0;
	static uint16_t ADC_high = 0;
	static uint16_t ADC_full = 0;
	
	ADC_low = ADCL;
	ADC_high = ADCH;
	ADC_full = (ADC_high << 8) | ADC_low;
	
	
	if ((ADMUX & 0x0F) == 1) {
		sum1 = sum1 - array1[i] + ADC_full;
		array1[i] = ADC_full;
		i = (i+1) % arr_size;
		ADC_full = sum1 / arr_size;		// rolling average found
		
		voltage = (Vcc / 1024.0)*ADC_full;		// normalize
		voltage = fabs(voltage - (Vcc / 2.0));
		current = voltage*9.752;	// 1/0.11 * 1000 --> new sensitivity with amplifier


		if (current > 22.3) {		// Thresholds
			current_alert_L.flag = 1;
			
			if (ADC_full < 512) {
				current_alert_L.sign = '-';
			}
			else {
				current_alert_L.sign = '+';
			}
			
			current_alert_L.data = current;
			
			
			//serial_transmit('M');
			//serial_transmit('1');
			//serial_transmit(':');
			//
			//if (ADC_full < 512) {
				//serial_transmit('-');
			//}
			//else {
				//serial_transmit('+');
			//}
			//
			//printFloat(current);
			//_delay_ms(150);
			//serial_transmit('?');
		}
		
		ADMUX = 0b01000010;		// switch to ADC2
	}
	else if ((ADMUX & 0x0F) == 2) {
		sum2 = sum2 - array2[i] + ADC_full;
		array2[i] = ADC_full;
		j = (j+1) % arr_size;
		ADC_full = sum2 / arr_size;
		
		voltage = (Vcc / 1024.0)*ADC_full;
		voltage = fabs(voltage - (Vcc / 2.0));
		current = voltage*9.752;


		if (current > 22.3) {		// Thresholds
			current_alert_R.flag = 1;
			
			if (ADC_full < 512) {
				current_alert_R.sign = '-';
			}
			else {
				current_alert_R.sign = '+';
			}
			
			current_alert_R.data = current;
			
			
			//serial_transmit('M');
			//serial_transmit('2');
			//serial_transmit(':');
			//
			//if (ADC_full < 512) {
				//serial_transmit('-');
			//}
			//else {
				//serial_transmit('+');
			//}
			//
			//printFloat(current);
			//_delay_ms(150);
			//serial_transmit('?');
		}
		
		ADMUX = 0b01000001;		// switch back to ADC1
	}
	else {
		ADMUX = 0b01000001;		// else set to ADC1
	}
}


#endif

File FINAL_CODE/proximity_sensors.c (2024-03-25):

/*
PD6 is Timer 0 Compare Match A Event				Drive train motor[s]L
PD5 is Timer 0 Compare Match B Event				Drive train motor[s]R

PB1 is Timer 1 Compare Match A Event				Deposition Bin deploy/retract
PB0 is Timer 1 Compare Match B Event				Deposition Bin doors:open/shut

PB3 is Timer 2 Compare Match A Event				Bucket Ladder deploy/retract
PD3 is Timer 2 Compare Match B Event				Bucket Ladder Chain start/stop/rvs


Author:												Stuart Pollmann
Program:											Stu-Bot Embedded
Application:										Robot Motions/Sensor reads
Use Case:											Brush DC Motor Control 
Functionality:										
Goal:												D-Pad implementation, then 
													joystick x/y axis differential
													drive train steering UART serial
													Sensor ADC Read channels multiplexed
													for multiple sensors, request/acknowledge
													for communication watchdog										
													
													
*/

#define F_CPU 16000000
#define BAUD_9_6K 9600								// define baud
#define BAUD_115K	115200
#define BAUDRATE ((F_CPU/(16UL*BAUD_9_6K))-1)		// set baud rate value for UBRR

#include <avr/io.h>
#include <avr/interrupt.h>

#define IN1AHI		(PORTC |= (1<<PINC1));			//For L Motors
#define IN2AHI		(PORTC |= (1<<PINC2));			//For L Motors
													//For L Motors
#define IN1ALOW		(PORTC &= ~(1<<PINC1));			//For L Motors
#define IN2ALOW		(PORTC &= ~(1<<PINC2));			//For L Motors

#define IN1BHI		(PORTC |= (1<<	PINC3));		//For R Motors
#define IN2BHI		(PORTD |= (1<<	PIND4));		//For R Motors
													//For R Motors
#define IN1BLOW		(PORTC &= ~(1<<	PINC3));		//For R Motors
#define IN2BLOW		(PORTD &= ~(1<<	PIND4));		//For R Motors

#define WinterIsCombing 0

#define FWD_DUTY	31;							//2ms
#define STOP_DUTY	23;							//1.5ms
#define RVRS_DUTY	15;							//1ms

#define DRIVE_L		OCR2A
#define DRIVE_R		OCR2B

#define EX_ACTUATOR	OCR0A
#define EX_ACTIVE	(PORTB |= (1<<PINB4));
#define EX_INACTIVE	(PORTB &= ~(1<<PINB4));

#define	EX_IN_PROG	(PORTD |= (1<<PIND7));

#define EX_CHAIN	OCR0B

#define zynOverDose	0;

volatile	uint8_t zyn4Scoobz = 0;
volatile	uint8_t DIRencoder = 0X00;
volatile	uint8_t NorthIsClear = 1;
volatile	char key = 0;

/*
#define ADC128		(1<<ADPS0)|(1<<ADPS1)|(1<<ADPS2)
#define StartADC	ADCSRA	|=	(1<<ADSC);
#define	ADCfreeRun	~(1<<ADTS0)&~(1<<ADTS1)&~(1<<ADTS2)

volatile uint8_t data_log[3] = {0,0,0};				//to hold packet content
char control[4]={'s', 'd', 'a', 'w'};	
uint8_t indexBuff = 0;
uint8_t com_state= 0;

#define JOY_R(x,y)	(((int8_t)y-127)-(((int8_t)x-127)>>1))
#define JOY_L(x,y)	(((int8_t)y-127)+(((int8_t)x-127)>>1))
*/

void ADC_init()									//Analogue Digital Conversion Set
{
	ADCSRA	|=	(1<<	ADEN)
			|(1<<		ADPS0)
			|(1<<		ADPS1)
			|(1<<		ADPS2)
			|(1<<		ADIE);					//Interrupt en

	ADMUX	&= ~(1<<	REFS1);					
	ADMUX	|=	(1<<	REFS0);					//Ref V cc setting

	ADMUX	&= ~(1<<	MUX0)						
			&  ~(1<<	MUX3);					 
	ADMUX	|=	(1<<	MUX1)
			|	(1<<	MUX2);					//ADC6 single ended input for
	ADMUX	|=	(1<<	ADLAR);					//Left justified
	ADCSRB	&=	~(1<<	ADTS0)
			&	~(1<<	ADTS1)
			&	~(1<<	ADTS2);					//ADTS0:2 = 0X00
}


void timer2_init()								//Drive train	
{
	TCCR2A	|=	(1<<	WGM21);					//Fast PWM
	TCCR2A	|=	(1<<	WGM20);
	TCCR2B	&= ~(1<<	WGM22);
	
	TCCR2B	|=	(1<<	CS22)
			|	(1<<	CS21)
			|	(1<<	CS20);					//PS 1024					
	
	TCCR2A	|=	(1<<	COM2B1);				//setting clears OCRB on
	TCCR2A	&= ~(1<<	COM2B0);				//compare match as well as
	TCCR2A	|=	(1<<	COM2A1);				//clears OCRA on compare
	TCCR2A	&= ~(1<<	COM2A0);				//match (CTC)
	
	TIMSK2	|=	(1<<	TOIE2);					//Max over flow enable
	
	OCR2A = STOP_DUTY
	OCR2B = STOP_DUTY
	
}

void timer0_init ()
{
	TCCR0A |=	(1<<WGM00)
		   |	(1<<WGM01);
		   
	TCCR0B	&= ~(1<<WGM02);
	
	TCCR0A |=  (1<< COM0A1)
		   |   (1<< COM0B1);
		   
	TCCR0A &= ~(1<<	COM0A0)
		   &  ~(1<<	COM0B0);
		   
	TCCR0B |=  (1<<	CS02)
		   |   (1<<	CS00);  
	TCCR0B &= ~(1<<	CS01);						//P.S. 1024
	
	OCR0A = STOP_DUTY
	OCR0B = STOP_DUTY
	
}

void timer1_init()
{
	
	TCCR1A	|=	(1<<	COM1A1	) 
			|	(1<<	COM1B1	);
			
	TCCR1A	&= ~(1<<	COM1A0	) 
			&  ~(1<<	COM1B0	);
	
	TCCR1A	|=	(1<<	WGM11	);
	TCCR1A	&=	~(1<<	WGM10	);
	TCCR1B	|=	(1<<	WGM12	)
			|	(1<<	WGM13	);
	
	TCCR1B	|=	(1<<	CS11	);
	TCCR1B	&= ~(1<<	CS10	)
			&  ~(1<<	CS12	);				//P.S.256
			
	//ICR1	=	0XC350;							//50,000 dec
	ICR1	=	5000;
	
	//OCR1A	=	25000;							//1.5ms
	OCR1A	=	2500;
	OCR1B	=	3000;							//3000 dec
	
}


void GPIO_init()								//Data Direction Set
{
	DDRC &=	~(1<<0);							//set for ADC Read
	DDRB|=	 (1<<3)
		|	 (1<<2)
		|	 (1<<1)
		|	 (1<<0);							//set for COMP2A PWM out
	DDRD|=	 (1<<3)
		|	 (1<<4)
		|	 (1<<5)
		|	 (1<<6);							//set for COMP2B PWM out
	
	
	DDRC|=	 (1<<1)
		|	 (1<<2)
		|	 (1<<3);							//set for Logic out IN1&2	
}

void SensorGPIO_Init()
{
	DDRD	&= ~(1<<2);							//For Proximity
	EICRA	|= (1<<ISC00);						//Vector Block
	EICRA	&= ~(1<<ISC01);
	EIMSK	|= (1<<INT0);						//D7 for North interrupt

	/*
	DDRD	&= ~(1<<2);					
	EICRA	|= (1<<ISC11) | (1<<ISC10);	
	EIMSK	= (1<<INT1);				
	*/

}

//** UART FUNCTIONS **//					
void uart_init (void)							// function to initialize UART
{

	//UBRR0H = (BAUDRATE>>8);					//shift the register right by 8 bits
	UBRR0L = 8;									// set lower baud rate to lower reg
												//USBSn =0 for 1 stop bit by default
												//UPMn1; UPMn0 are 0 by default pairty disabled
	
	UCSR0B	|=	(1<<	TXEN0)
			|	(1<<	RXEN0)
			|	(1<<	RXCIE0);				// enable receiver and transmitter
	
	UCSR0C	|=	(1<<	UCSZ00)
			|	(1<<	UCSZ01);				//reg C UCSZn1&n0 should be 1 for 8-bit char size

}

void serial_transmit (unsigned char data)		//Tx serial
{ 

	while (!( UCSR0A & (1<<UDRE0)));			//w8 b4 read;
												//UDREn is read when 1	
	UDR0 = data; 								//write the data in register

}

unsigned char uart_recieve (void)				//Rx serial
{
	
	while(!((UCSR0A) & (1<<RXC0)));				// wait while data is being received
	return UDR0;								// return 8-bit data read

}

void term_Send_Val_as_Digits(uint8_t val)		//Decimal
{
	uint8_t digit = '0';						//Initialize
	
	while(val >= 100)							//incoming hundred's
	{
		digit	+= 1;							//count
		val		-= 100;							//chunks of hundred
	}
	
	serial_transmit(digit);						//Send to serial

	digit = '0';								//initialize
	
	while(val >= 10)							//Remaining ten's
	{
		digit	+= 1;							//count 
		val		-= 10;							//chunks of ten
	}
	
	serial_transmit(digit);						//Send to Serial
	
	serial_transmit('0' + val);					//Send remainder Value
												//from ascii: '0'
}

void printBin8(uint8_t stuff)					//Binary Print
{
	for(uint8_t n = 0; n < 8; n++)				//Print data: MSB to LSB
	{
		uint8_t tm_ = (stuff >> (7 - n)) & (0x01);
												//shift highest 
												//AND remaining
		if(tm_)
		{
			serial_transmit('1');				//Send 1
		} 
		else 
		{
			serial_transmit('0');				//Send 0
		}
	}
}												
//** END UART FUNCTIONS **//															

void init_DIR()									//Initiallize DIR to stop
{
	IN1ALOW
	IN2ALOW
	IN1BLOW
	IN2BLOW
}
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

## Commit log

2023-10-20 Create main.c
    This program generates a signal to drive TB6612FNG H-Bridge. w/e drives motors lolz
2023-10-25 Create CAD
2023-10-29 Create ADC HBridge Driver.c
2023-11-03 Create 12V 100W 8 Nm motor.SLDPRT
    [12V 100W 8 Nm motor.SLDPRT]
2023-11-03 Create 24V 80 W 6Nm Brush.SLDPRT
    [24V 80 W 6Nm Brush.SLDPRT]
2023-11-06 Rough Design
    [47065T411_T-Slotted Framing.SLDPRT, Simple Model.SLDASM]
2023-11-06 Create UART HBridge Driver.c
    This is a mess. Program works w Putty, Terra Term- Interrupt driven... w/e. still needs a watch dog mechanism
2023-11-06 Create HADES
    HADES CAD models
2023-11-06 added HADES CAD
    * HADES CAD files
    [1549A57_Strap Hinge.SLDPRT, 1549A57_Strap Hinge2.SLDPRT, 2452K39_Corrosion-Resistant Roller Chain Attachment Link.SLDPRT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]
2023-11-08 Create LED board.kicad_pro
2023-11-08 for a 1ft wheel with 18 grousers, bad screws
    [Full Grouser Wheel 18Grouser.SLDASM, Grouser Wheel 20Degree.SLDPRT, Grouser Wheel Rim front.SLDPRT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]
2023-11-10 Wield Excavation
    [1497K61_1045 Carbon Steel Keyed Rotary Shaft (1).SLDPRT, 2ft-9056K324_Multipurpose 6061 Aluminum Round Tube.SLDPRT, 2ft-9056K512_Multipurpose 6061 Aluminum Rou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]
2023-11-20 Create serial_blink.py
    Python script that can send serial data to an Arduino that is expecting that data
2023-11-25 Create switch_networks.sh
    Has error when running on ssh connection that disconnects
2023-11-25 Create serial_gamepad.py
    No serial comms yet, only a subber that grabs the button data being published by /joy
2023-11-27 Drivetrain & linear actuators controls work via Dpad & bumpers & trigger
2023-11-27 code for drivetrain & excavator linear actuators added
2023-12-05 Corrected if-statements for DPad control and linear actuators
2023-12-12 File organization for stem_engagement
    [UART HBRIDGE DRIVER - STEM ENGAGEMENT.kicad_pcb, UART HBRIDGE DRIVER - STEM ENGAGEMENT.kicad_sch]
2023-12-12 schematic with L298N motor driver
    [L298N_motor_driver.kicad_sch]
2023-12-12 file organization
    Put .ino file in a dir of the same name so that the .ino file can be opened by the Arduino IDE
2023-12-15 Update
    State Machine removed, faster. Pullup enable, less dumb. = def not |=, syntax killer of champions
    [Load Cell Part.SLDPRT]
2023-12-28 Create System Circuit v1.0.kicad_sch
    [System Circuit v1.0.kicad_sch]
2024-01-08 meh
    some ft prints are customized
    [System Circuit Low Level 1.2.kicad_pcb, System Circuit Low Level 1.2.kicad_sch, System Circuit Low w Periph.kicad_sch]
2024-02-08 add comments to describe pipeline
    [System Circuit Low w Periph.kicad_sch]
2024-02-09 UART Rx for receiving 16 bit values (joystick values)
2024-02-09 added joystick in deadzone case
2024-02-13 comments, refactoring, error message printing
2024-02-14 normalize & send motor values to Arduino
    normalize motor values in prep to send to Arduino, send motor values in accordance to C msg_handler() protocol
2024-02-16 added UART0_RX ISR
2024-02-16 Create ASC758 driver 16.c
    This right justified program uses breadth of ADC to read 2 current sensors alternating. Where 15 integers of range is thin for change in current (510-525), it's better than the (127-131) for a current domain of 0-1.6A. because motors are 4amps under no load, up to 20 amps sufficiently loaded, this program should operate 510-710 integer with no differential circuitry or change in reference voltage. Efforts to improve circuits are being investigated, Stu no longer developing this program.
    [ASC758 driver 16.c]
2024-02-20 added serial prints for testing
    trying to solve soft reset problem
2024-02-21 case 2 update
    msg_handler() should now be working correctly for case 2
2024-02-21 current sensor code attempt
2024-02-29 Fixed bytes & order of sending
    [serial_joystick.py]
2024-02-29 fixed wrong deadzone vals
    [serial_joystick.py]
2024-03-01 Added Vulcan's camera stream code
2024-03-04 printing in binary
2024-03-06 Upload initial ROS2 current sensor code.
2024-03-06 sends bytes correctly, baud change
    [serial_joystick.py]
2024-03-06 Update CurrensSensorROSSubber.py
    Fixed upload
    [CurrensSensorROSSubber.py]
2024-03-07 Root Cause
    Segregated, per data sheet async require 2 U2X0, why factors of double the BAUD worked, increase the divider to return to 115200 BAUD, hard reset on the Arduino will reliably flush UDR0 register yielding no prior receive data on serial terminal start up *on Terra Term*
    [Fuck this.c]
2024-03-07 Update CurrensSensorROSPublisher.py
    Simple bug fixes
    [CurrensSensorROSPublisher.py]
2024-03-07 Update CurrensSensorROSSubber.py
    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
    [CurrensSensorROSSubber.py]
2024-03-07 added the camera stuffs
2024-03-13 watchdog does not interrupt controls
2024-03-13 started button code
2024-03-14 Updated Current Sensor ROS code
2024-03-15 Update CurrensSensorROSSubber.py
    Fixed the dumb file
    [CurrensSensorROSSubber.py]
2024-03-15 Update CurrensSensorROSSubber.py
    Debugged Current Sensor so it now compiles. Also noticed that the file name has a typo in it ;(
2024-03-15 Update CurrensSensorROSPublisher.py
    Fixed the callback. Code now comiles
    [CurrensSensorROSPublisher.py]
2024-03-22 Update current_sensor.c
    Switches between ADC2 and ADC3, new sensitivity with amplifier
2024-03-22 created button control code
    also changed init_DIR() to 2 separate functs
    [System Circuit v1.0.kicad_sch]
2024-03-22 revert: comparision put back in send_dut_vals()"
    [serial_joystick.py]
2024-03-25 current sensor pubber integration started
2024-03-26 mistake fix, sends deadzone motor vals now
    [serial_joystick.py]
2024-03-28 PWM val fixed; depo bin tilt pin changed
2024-04-03 mistake found, sent bytes twice ???
    [serial_joystick.py]
2024-04-03 Update current_sensor.c for Arduino Mega
2024-04-06 Put watchdog reset in msg_handler & added double buttons
    also changes some LA speeds to half speed
2024-04-14 started priority scheduling & current sensor polling
2024-04-16 reorganize & wrote .md readme
    [12V 100W 8 Nm motor.SLDPRT, 24V 80 W 6Nm Brush.SLDPRT, L298N_motor_driver.kicad_sch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]
2024-04-16 added Arduino hat help
2024-04-16 Revert "Squashed commit of the following:"
    This reverts commit 0ca7ddda6cd4e5faa59e093bc2a898d7b326d731.
    [12V 100W 8 Nm motor.SLDPRT, 24V 80 W 6Nm Brush.SLDPRT, L298N_motor_driver.kicad_sch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]
2024-04-18 working threshold alerts for current sensors
2024-04-18 Create CAM_srvo.c
    Rough draft of motors on camera
2024-05-02 Initializes with rover drivetrain stopped
2024-05-03 support gimble servos
2024-05-04 Gimble servos init correctly
2024-05-15 Reapply "Squashed commit of the following:"
    This reverts commit 8523155ff6cc300d5b31a5990088b6d4260c5c95.
    [12V 100W 8 Nm motor.SLDPRT, 24V 80 W 6Nm Brush.SLDPRT, L298N_motor_driver.kicad_sch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]
2024-06-06 add button mappings
